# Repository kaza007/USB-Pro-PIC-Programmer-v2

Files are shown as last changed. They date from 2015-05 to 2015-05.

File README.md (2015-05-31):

# USB-Pro-PIC-Programmer-v2
OshonSoft Compatible USB PIC Programmer

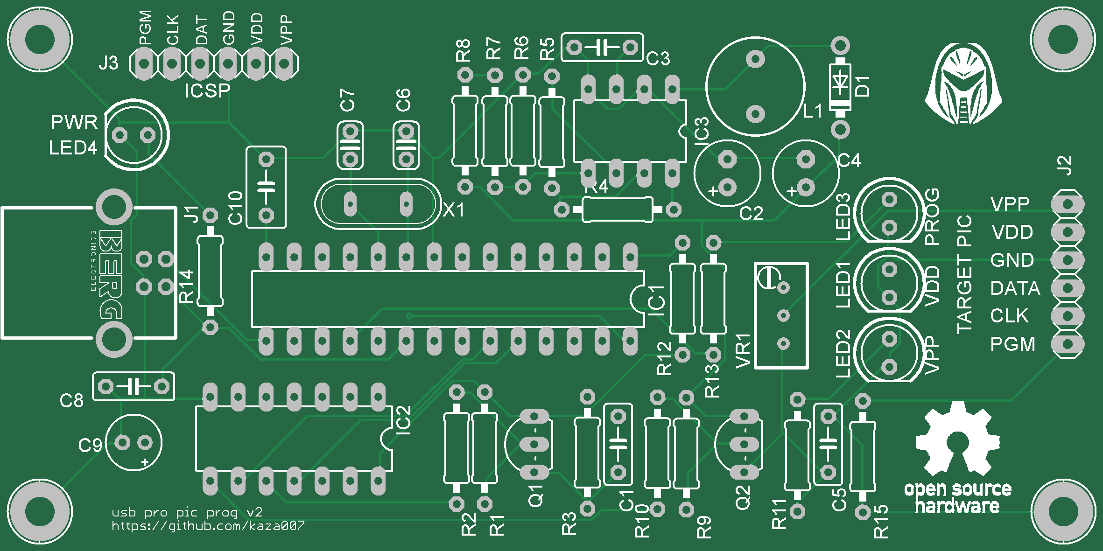
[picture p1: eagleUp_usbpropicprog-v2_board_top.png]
PCB


Background
----------
The USB Pro PIC-PIC18-PIC16-AVR programmer is an [*open project*](http://www.oshonsoft.com/picprogprousb.html) created by Vladimir Soso, the author of the PIC Simulator IDE at [*OshonSoft.com*](http://www.oshonsoft.com/).

This project is a PCB for the USB Pro PIC Programmer with added DC-DC converter. The programmer can now be powered by the USB port without the use of an external power supply. The PCB is also very easy to assemble as all the components are *through hole* type.

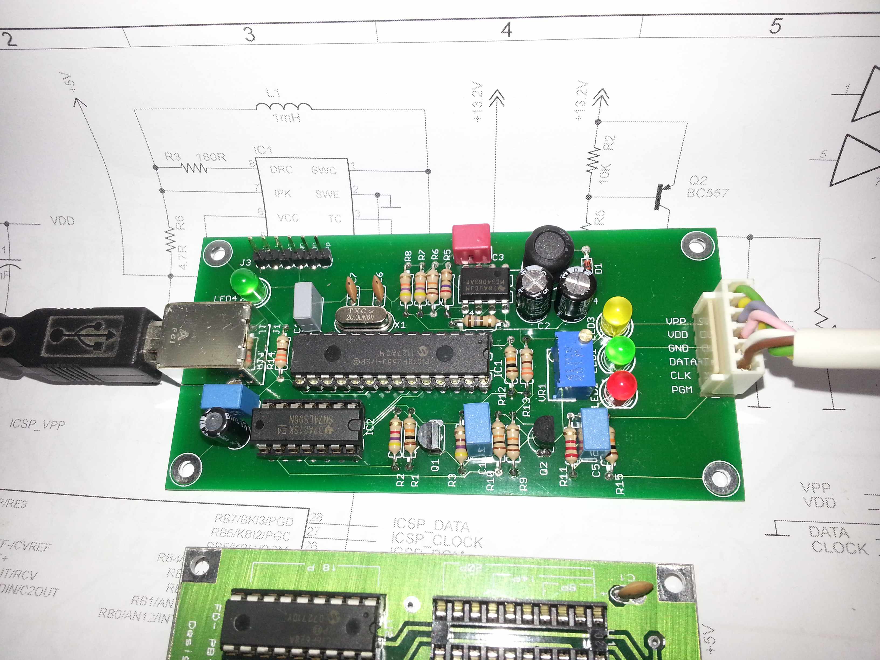
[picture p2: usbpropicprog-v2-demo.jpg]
Demo


Design Software
-----------------
This project was designed with [Eagle](http://www.cadsoftusa.com/) 7.2.0, [Sketchup](http://www.sketchup.com/) 15.3.331 and [EagleUp](http://eagleup.wordpress.com) 4.5.

License
-------


This work is licensed under a [Creative Commons Attribution-ShareAlike 4.0 International License](<http://creativecommons.org/licenses/by-sa/4.0/).

Original design by: Vladimir Soso, [*OshonSoft.com*](http://www.oshonsoft.com/).

Modified by: [*https://github.com/kaza007*](https://github.com/kaza007)

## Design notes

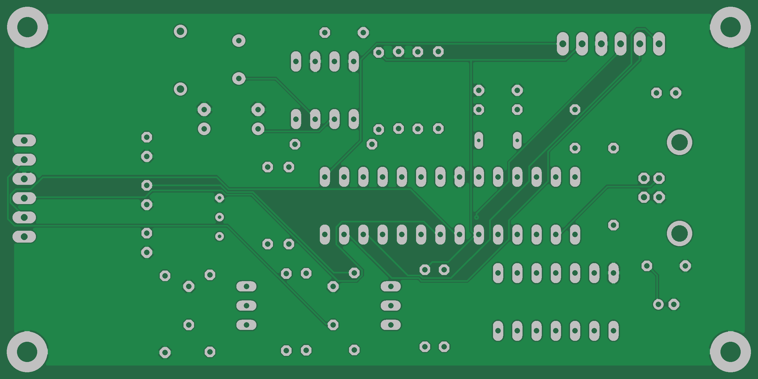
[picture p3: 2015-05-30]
eagleUp_usbpropicprog-v2_board_bottom.png

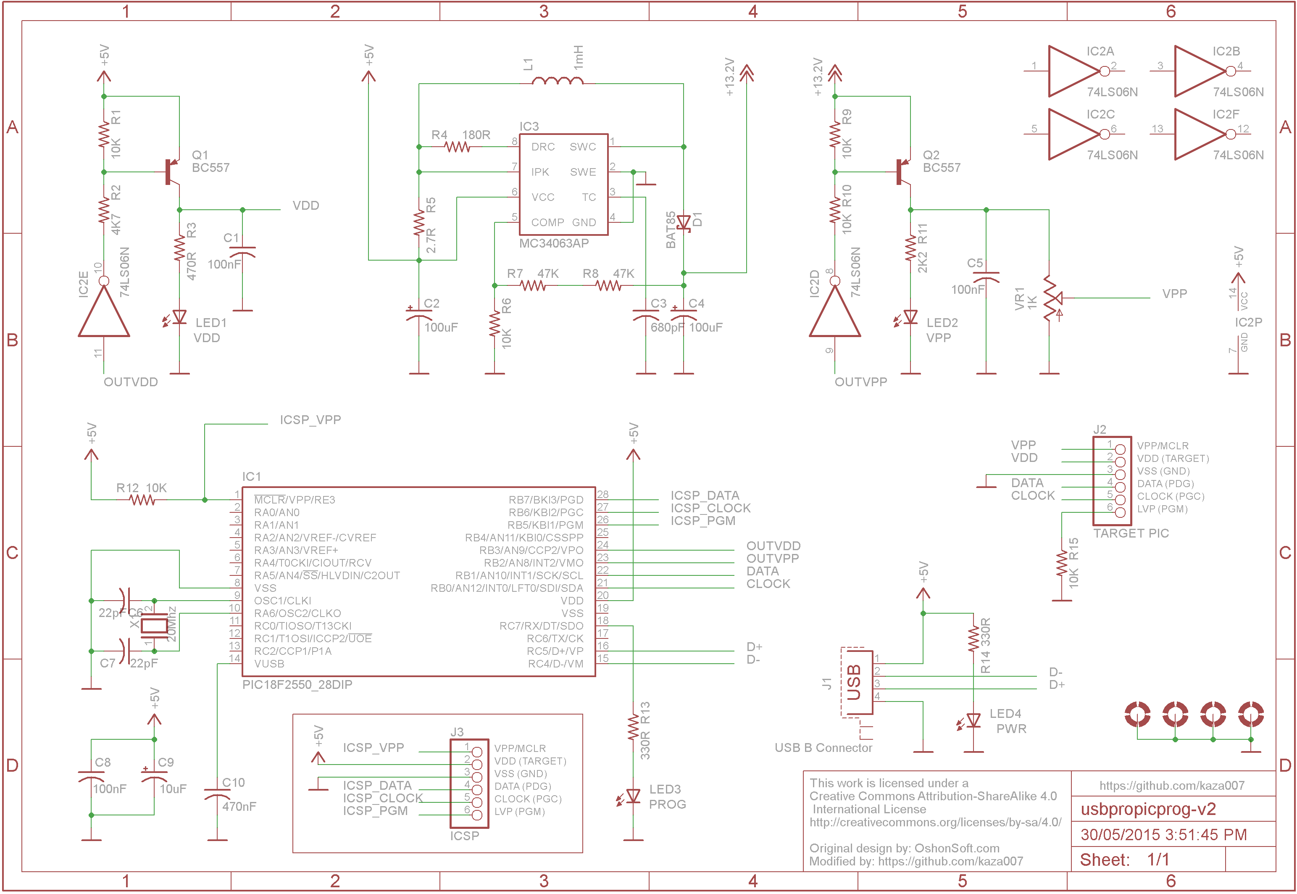
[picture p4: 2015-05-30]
usbpropicprog-v2.sch.png

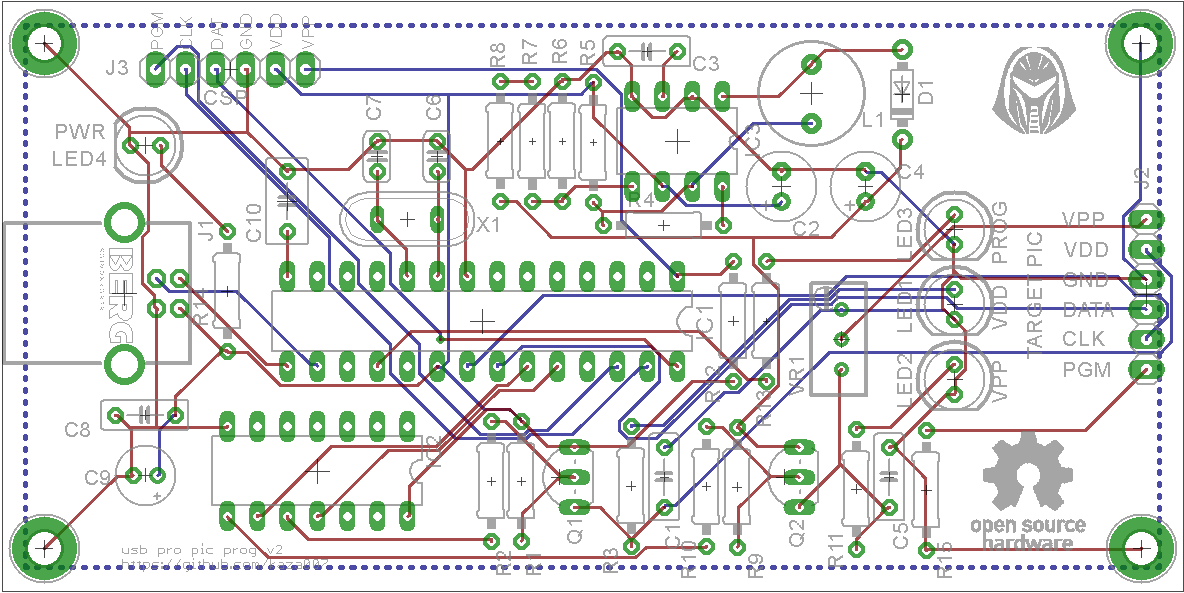
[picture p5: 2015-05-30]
usbpropicprog-v2.brd.png

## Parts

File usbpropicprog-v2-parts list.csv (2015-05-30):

 |  |  | element14 |  | digikey
part | qty | desc | Part number | order code | manufacturers part number | digikey part nuber
VR1 | 1 | TRIMMER, 25 TURN 1K | T93YA102KT20 | 1141401 | T93YA102KT20 | T93YA-1.0K-ND
J1 | 1 | CONNECTOR, USB B, RECEPTACLE, PCB, R/A | 61729-0010BLF | 1097897 | 61729-0010BLF | 609-1039-ND
J3 | 1 | BOARD TO BOARD, HEADER, 6POS, 1ROW | 68000-206HLF | 1924233 | 68000-206HLF | 609-3256-ND
J2 | 1 | HEADER, SQUARE PIN, 2.54MM, 6WAY | 22-27-2061 | 9731172 | 640456-6 | A1923-ND
C1;C5;C8 | 3 | CAPACITOR PEN FILM, 0.1UF, 100V, 10%, RADIAL | B32529C1104K | 2098447 | B32529C1104K | 495-2481-ND
C10 | 1 | CAP, FILM, PET, 470NF, 63V, RAD | BFC237011474 | 1215513 | B32529C474K | 495-2561-ND
D1 | 1 | DIODE, SCHOTTKY, 200M, 30V, DO-34 | BAT85,113 | 1097299 | BAT85,113 | 568-1617-1-ND
Q1;Q2 | 2 | TRANSISTOR, PNP, 45V, 0.1A, TO-92 | BC557BZL1G | 9558527 | BC557BZL1G | BC557BZL1GOSCT-ND
R1;R6;R9;R10;R12;R15 | 6 | RESISTOR, CARBON , 10K, 0.33W, 5% | CFR25J10K | 2329609 | CFR-25JB-52-10K | 10KQBK-ND
R4 | 1 | RESISTOR, CARBON , 180R, 0.33W, 5% | CFR25J180R | 2329623 | CFR-25JB-52-180R | 180QBK-ND
R11 | 1 | RESISTOR, CARBON , 2K2, 0.33W, 5% | CFR25J2K2 | 2329653 | CFR-25JB-52-2K2 | 2.2KQBK-ND
R13;R14 | 2 | RESISTOR, CARBON , 330R, 0.33W, 5% | CFR25J330R | 2329663 | CFR-25JB-52-330R | 330QBK-ND
R3 | 1 | RESISTOR, CARBON , 470R, 0.33W, 5% | CFR25J470R | 2329680 | CFR-25JB-52-470R | 470QBK-ND
R2 | 1 | RESISTOR, CARBON , 4K7, 0.33W, 5% | CFR25J4K7 | 2329685 | CFR-25JB-52-4K7 | 4.7KQBK-ND
R5 | 1 | RESISTOR, CARBON , 2R7, 0.33W, 5% | CFR25J2R7 | 2329660 | CFR-25JB-52-2R7 | 2.7QBK-ND
R7;R8 | 2 | RESISTOR, CARBON , 47K, 0.33W, 5% | CFR25J47K | 2329681 | CFR-25JB-52-47K | 47KQBK-ND
C6;C7 | 2 | CAPACITOR CERAMIC 22PF 50V, C0G/NP0, 5%, RAD | MCCC50V220JNPO | 1600966 | DEA1X3D220JC1B | 490-4175-ND
X1 | 1 | XTAL, 20.000MHZ, 18PF, HC-49S | 9B-20.000MAAJ-B | 1842224 | 9B-20.000MAAJ-B | 887-1023-ND
IC3 | 1 | IC, DC/DC CONTROLLER, 34063, DIP8 | MC34063AP | 1053579 | MC34063AP | 296-17766-5-ND
C3 | 1 | CAP, FILM, PP, 680PF, 100V, RAD | FKP2D006801D00JSSD | 1005990 | PFR5681J63J11L4BULK | 399-7706-ND
IC1 | 1 | MCU, 8BIT, PIC18, 48MHZ, NDIP-28 | PIC18F2550-I/SP | 9321250 | PIC18F2550-I/SP | PIC18F2550-I/SP-ND
IC2 | 1 | LOGIC, BUFF/DVR HEX INVERT, 14DIP | SN74LS06N | 1739683 | SN74LS06N | 296-15069-5-ND
C9 | 1 | CAPACITOR ALUM ELEC 10UF, 35V, 20%, RADIAL | UVR1V100MDD1TD | 1822563 | UVR1V100MDD | 493-1077-ND
C2;C4 | 2 | CAPACITOR ALUM ELEC 100UF, 35V, 20%, RADIAL | UVR1V101MED1TD | 1822582 | UVR1V101MED | 493-1081-ND
LED1;LED4 | 2 | LED, 5MM, GREEN, 100MCD, 568NM | L-1503GD | 2335726 | WP7113GD | 754-1263-ND
LED2 | 1 | LED, 5MM, RED, 40MCD, 617NM | L-1503ID | 2335725 | WP7113ID | 754-1264-ND
LED3 | 1 | LED, 5MM, YELLOW, 30MCD, 588NM | L-1503YD | 2335727 | WP7113YD | 754-1284-ND
L1 | 1 | INDUCTOR, 1MH, RADIAL LEADED | RLB0912-102KL | 1795352 | RLB0912-102KL | RLB0912-102KL-ND

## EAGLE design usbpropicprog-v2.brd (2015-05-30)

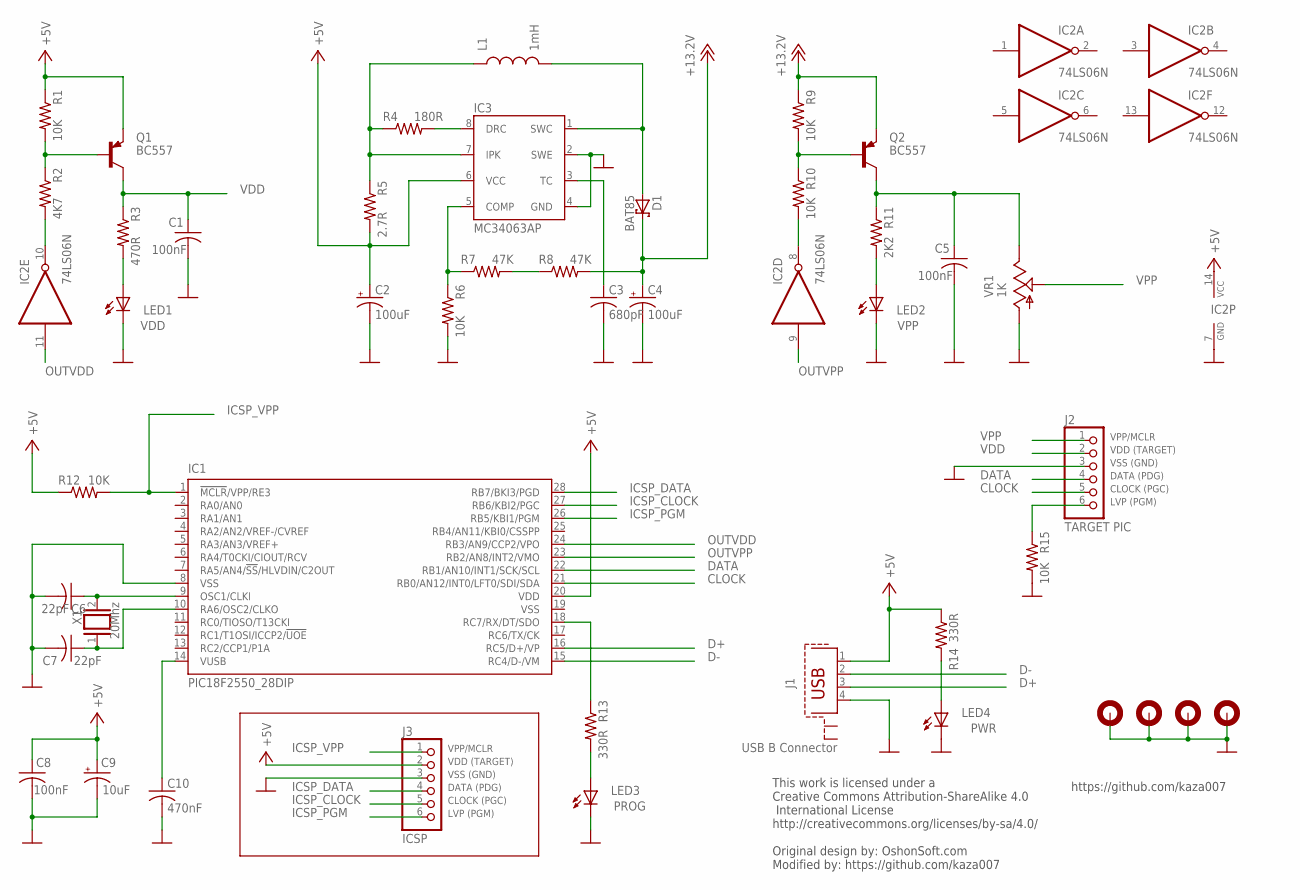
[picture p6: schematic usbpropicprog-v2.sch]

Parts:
C1, C5, C8: 100nF; C050-025X075
C2, C4: 100uF; E2,5-6,3
C3: 680pF; C050-025X075
C6, C7: 22pF; C025-024X044
C9: 10uF; E2-5
C10: 470nF; C050-035X075
D1: BAT85; DO41-7.6
H1, H2, H3, H4: MOUNT-PAD-ROUND2.8; 2,8-PAD
IC1: PIC18F2550_28DIP; DIL28-3
IC2: 74LS06N; DIL14
IC3: MC34063AP; DIL-08
J1: USB B Connector; PN61729-S
J2: TARGET PIC; 1X06
J3: ICSP; 1X06
L1: 1mH; RLB0912
LED1: VDD; LED5MM
LED2: VPP; LED5MM
LED3: PROG; LED5MM
LED4: PWR; LED5MM
Q1, Q2: BC557; TO92-EBC
R1, R6, R9, R10, R12, R15: 10K; 0207/10
R2: 4K7; 0207/10
R3: 470R; 0207/10
R4: 180R; 0207/10
R5: 2.7R; 0207/10
R7, R8: 47K; 0207/10
R11: 2K2; 0207/10
R13, R14: 330R; 0207/10
VR1: 1K; R-TRIMMT93YA
X1: 20Mhz; QS

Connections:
+5V: C2.+, C8.1, C9.+, IC1.20 (VDD), IC2.14 (VCC), IC3.6 (VCC), J1.1, J3.2, Q1.E, R1.1, R5.2, R12.1, R14.1
+12V: C4.+, D1.C, Q2.E, R8.2, R9.1
CLOCK: IC1.21 (RB0/AN12/INT0/LFT0/SDI/SDA), J2.5
D+: IC1.16 (RC5/D+/VP), J1.3
D-: IC1.15 (RC4/D-/VM), J1.2
DATA: IC1.22 (RB1/AN10/INT1/SCK/SCL), J2.4
GND: C1.2, C2.-, C3.2, C4.-, C5.2, C6.2, C7.2, C8.2, C9.-, C10.2, H1.B2,8, H2.B2,8, H3.B2,8, H4.B2,8, IC1.8 (VSS), IC2.7 (GND), IC3.2 (SWE), IC3.4 (GND), J1.4, J2.3, J3.3, LED1.K (C), LED2.K (C), LED3.K (C), LED4.K (C), R6.2, R15.2, VR1.3 (A)
ICSP_CLOCK: IC1.27 (RB6/KBI2/PGC), J3.5
ICSP_DATA: IC1.28 (RB7/BKI3/PGD), J3.4
ICSP_PGM: IC1.26 (RB5/KBI1/PGM), J3.6
ICSP_VPP: IC1.1 (!MCLR!/VPP/RE3), J3.1, R12.2
unnamed: IC1.18 (RC7/RX/DT/SDO), R13.1
unnamed: LED3.A, R13.2
unnamed: R7.2, R8.1
unnamed: J2.6, R15.1
unnamed: LED4.A, R14.2
unnamed: Q1.B, R1.2, R2.1
unnamed: Q2.B, R9.2, R10.1
unnamed: IC3.8 (DRC), R4.2
unnamed: LED1.A, R3.2
unnamed: IC3.7 (IPK), L1.1, R4.1, R5.1
unnamed: IC2.10 (O), R2.2
unnamed: LED2.A, R11.2
unnamed: C6.1, IC1.9 (OSC1/CLKI), X1.2
unnamed: C10.1, IC1.14 (VUSB)
unnamed: IC2.8 (O), R10.2
unnamed: D1.A, IC3.1 (SWC), L1.2
unnamed: C3.1, IC3.3 (TC)
unnamed: IC3.5 (COMP), R6.1, R7.1
unnamed: C7.1, IC1.10 (RA6/OSC2/CLKO), X1.1
OUTVDD: IC1.24 (RB3/AN9/CCP2/VPO), IC2.11 (I)
OUTVPP: IC1.23 (RB2/AN8/INT2/VMO), IC2.9 (I)
VDD: C1.1, J2.2, Q1.C, R3.1
VPP: J2.1, VR1.2 (S)
VPPHIGH: C5.1, Q2.C, R11.1, VR1.1 (E)
VSS: IC1.19 (VSS)

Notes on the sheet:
VPP/MCLR
VDD (TARGET)
VSS (GND)
DATA (PDG)
CLOCK (PGC)
LVP (PGM)
https://github.com/kaza007
This work is licensed under a Creative Commons Attribution-ShareAlike 4.0 International License http://creativecommons.org/licenses/by-sa/4.0/ Original design by: OshonSoft.com Modified by: https://github.com/kaza007

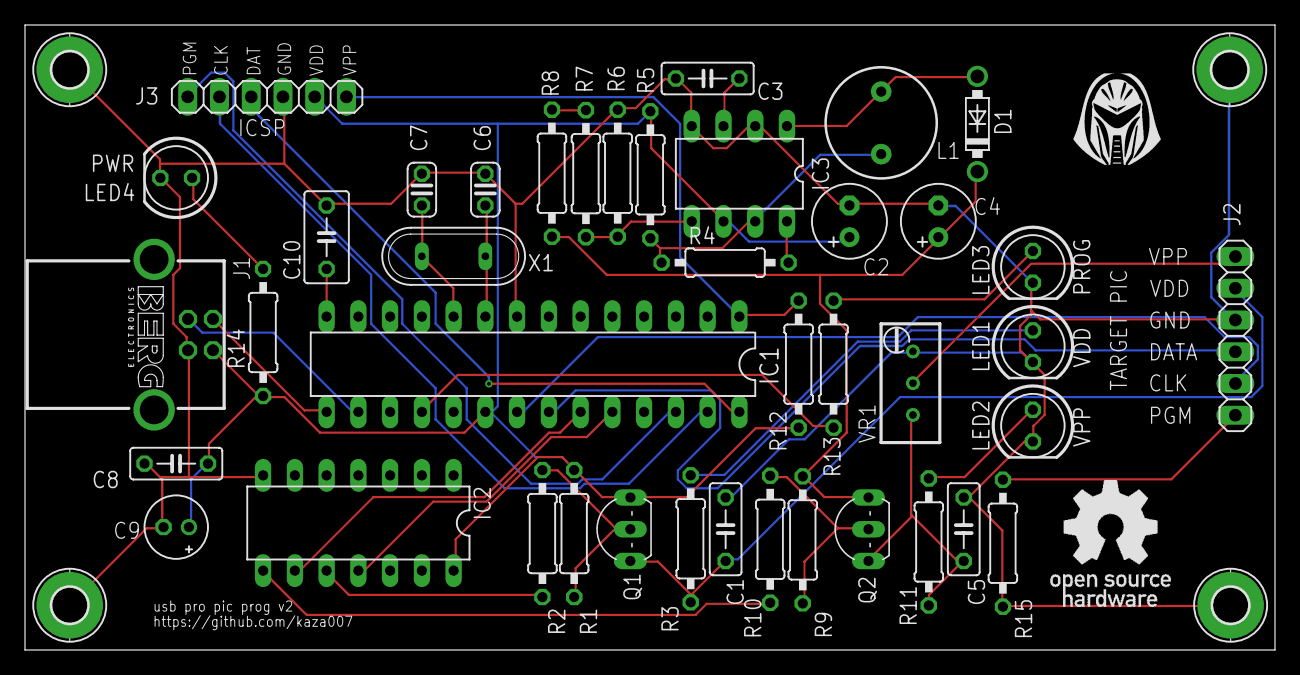
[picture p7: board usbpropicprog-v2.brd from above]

Board: 2 copper layers, 100.0 x 50.0 mm, 45 parts (0 on the bottom side), 35 nets.

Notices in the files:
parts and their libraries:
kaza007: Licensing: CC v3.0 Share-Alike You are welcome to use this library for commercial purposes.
